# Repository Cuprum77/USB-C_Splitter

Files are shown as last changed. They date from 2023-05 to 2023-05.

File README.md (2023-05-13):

# USB-C_Splitter

This project is a simple solution to the problem of working with USB-PD devices on a computer that does not have a USB-PD capable port. By splitting off the standard USB 2.0 data lines to a seperate port, with only a shared ground connection. We can experiment and develop with USB PD devices on any computer with a USB 2.0 port even if it does not support USB PD.

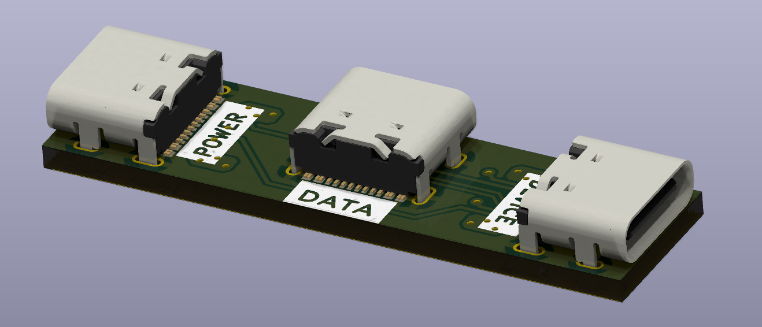
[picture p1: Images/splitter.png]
USB-C Splitter


## How to get one
Place an order at your favorite board house using the [gerber files](production/gerber.zip) in the [production](production/) folder.
Get 3 USB-C 2.0 connectors from GCT with the model number `USB4105-GF-A-120`.
Soldering should be possible by hand, although it will require a steady hand, lots of flux and a decent soldering iron. The USB-C connectors are quite small and have a lot of pins. If you are not comfortable soldering SMD components, you can always order the board with assembly from your favorite board house.

## How to use
Simply plug in your USB-PD capable device in the "Device" port, plug a cable to your computer into the "Data" port and the remaining "Power" port is now available for you to use to power your device. All ports are USB-C 2.0 compliant and should support USB 2.0 speeds.

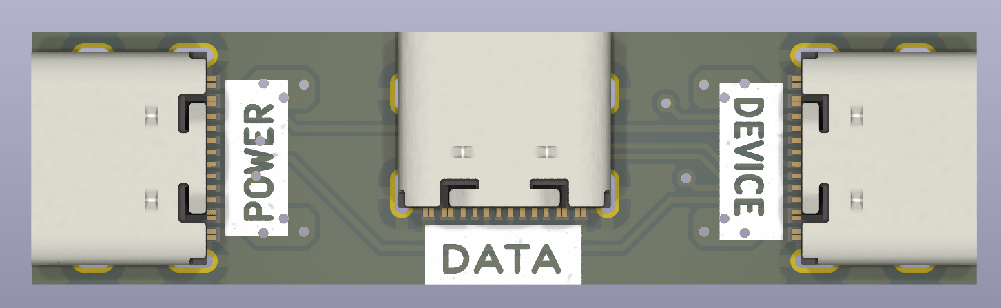
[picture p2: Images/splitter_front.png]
USB-C Splitter

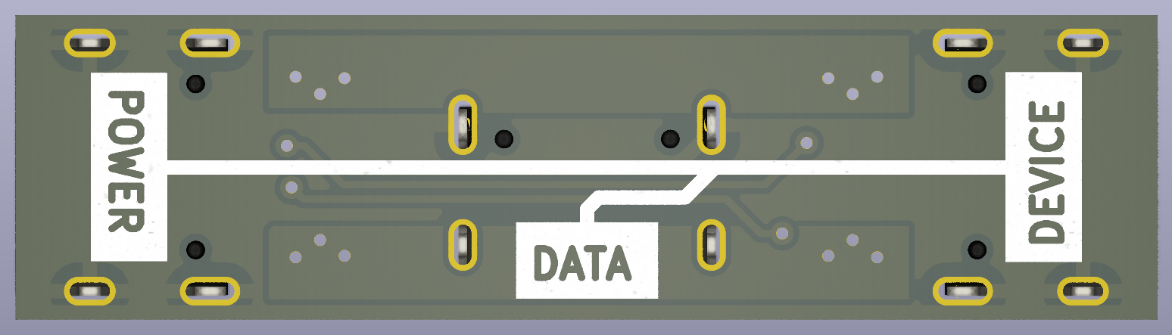
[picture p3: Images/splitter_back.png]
USB-C Splitter


## License
This project is licensed under the CERN License - see the [LICENSE](LICENSE) file for details

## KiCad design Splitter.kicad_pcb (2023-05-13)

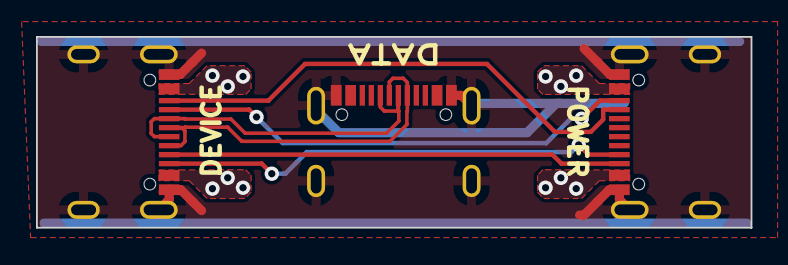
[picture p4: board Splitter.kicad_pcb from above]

Board: 2 copper layers, 39.7 x 10.6 mm, 3 parts (0 on the bottom side), 8 nets.

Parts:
J1, J2, J4: USB4105-GF-A-120; USB_C_Receptacle_GCT_USB4105-xx-A_16P_TopMnt_Horizontal

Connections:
/CC1: J1.A5 (CC1), J2.B5 (CC2)
/CC2: J1.B5 (CC2), J2.A5 (CC1)
/D+: J1.A6 (D+), J1.B6 (D+), J4.A6 (D+), J4.B6 (D+)
/D-: J1.A7 (D-), J1.B7 (D-), J4.A7 (D-), J4.B7 (D-)
/SBU1: J1.A8 (SBU1), J2.B8 (SBU2)
/SBU2: J1.B8 (SBU2), J2.A8 (SBU1)
/VBUS: J1.A4 (VBUS), J1.A9 (VBUS), J1.B4 (VBUS), J1.B9 (VBUS), J2.A4 (VBUS), J2.A9 (VBUS), J2.B4 (VBUS), J2.B9 (VBUS)
GND: J1.A1 (GND), J1.A12 (GND), J1.B1 (GND), J1.B12 (GND), J1.S1 (SHIELD), J2.A1 (GND), J2.A12 (GND), J2.B1 (GND), J2.B12 (GND), J2.S1 (SHIELD), J4.A1 (GND), J4.A12 (GND), J4.B1 (GND), J4.B12 (GND), J4.S1 (SHIELD)
